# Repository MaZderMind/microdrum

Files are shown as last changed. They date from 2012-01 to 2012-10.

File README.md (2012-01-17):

# MicroDrum - Ein Mikrocontroller-Basierter Drum-Computer
Dies ist das Sourcecode-Repo des [Microdum-Projektes](http://microdrum.wordpress.com/). Die Hardware-Spezifikationen und Software-Komponenten werden hier veröffentlicht, Hintergründe und Geschichte können im [Blog](http://microdrum.wordpress.com/) nachgelesen werden.

## Kontakt
Wenn du Fragen hast, melde dich bei microdrum@mazdermind.de oder benutze das Github-Nachrichten-System

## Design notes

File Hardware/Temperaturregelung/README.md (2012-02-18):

# Anschlussplan für Temperaturregelung für Laminator
Dies ist der Schaltplan für die Temperaturregelung des Laminators verwendet wurde, mit welchem die Platinen des Drumcomputers hergestellt wurden.
Verwendet wird ein ATtiny13 zur Steuerung, eine 1N4148-Diode als Temperatursensor und ein S202S02 Optotriac zum steuern der Heizung.
Mehr Infos über den Aufbau des Gerätes können im [Blog](http://microdrum.wordpress.com/2012/02/17/platinen-herstellen/) gefunden werden, die ursprüngliche Idee und Umsetzung stammt von [Thomas Pfeifer](http://thomaspfeifer.net/laminator_temperatur_regelung.htm).

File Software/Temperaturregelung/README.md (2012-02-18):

# Temperaturregelung für Laminator
Dies ist die Software des ATtiny13, welcher für die Temperaturregelung des Laminators verwendet wurde, mit welchem die Platinen des Drumcomputers hergestellt wurden.
Wichtig ist, dass der ATtiny13 auf 4.8 MHz internen Resonator gestellt wird, da sonst die timings für den Software-UART zu ungenau sind. Gegebenenfalls muss ein externer Quarzoszialtor verwendet werden.
Mehr Infos über den Aufbau des Gerätes können im [Blog](http://microdrum.wordpress.com/2012/02/17/platinen-herstellen/) gefunden werden, die ursprüngliche Idee und Umsetzung stammt von [Thomas Pfeifer](http://thomaspfeifer.net/laminator_temperatur_regelung.htm).

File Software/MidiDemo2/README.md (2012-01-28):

# MidiDemo 2
Sendet im durch den Host-Computer vorgegeben Takt eine Midi-Note, wobei die Instrumente zwischen 35 und 59 durchlaufen werden.
In dieser Demo wird der Sende- und der Empfangsteil verwendet. Für weitere Informationen bitte das [Blog](http://microdrum.wordpress.com/2012/01/18/prototyp/) konsultieren.

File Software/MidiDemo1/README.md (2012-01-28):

# MidiDemo 1
Sendet im 1/4 Sekunden Takt eine Midi-Note an den Host-Computer, wobei die Instrumente zwischen 35 und 59 durchlaufen werden.
In dieser Demo wird nur der Sendeteil verwendet. Für weitere Informationen bitte das [Blog](http://microdrum.wordpress.com/2012/01/18/prototyp/) konsultieren.

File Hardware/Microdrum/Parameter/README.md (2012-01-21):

# MicroDrum - Parameter-Board
Dieser Ordner enthält Schemazeichnung und Platinenlayouts für die Parameter-Boards. Ein solches Board ist mit je 16 Drehpotentiometern bestückt und bietet dem Nutzer die Möglichkeit, die Klang-Parameter der einzelnen Instrumente zu konfigurieren.

## Aufbau
Damit der Atmel so viele analoge Signale (8×4 = 32) überhaupt verarbeiten kann, kommen [74HC4051](http://www.datasheetcatalog.org/datasheet/philips/74HC4051.pdf) 8-Kanal Analog Multiplexer/Demultiplexer zum Einsatz. Bei diesen Bauteilen wird mit 3 digitalen Leitungen einer der 8 Eingangspins gewählt, welcher dann mit dem Ausgangsport verbunden wird.

Wir verwenden 4 solcher ICs, deren Auswahlports jeweils verbunden sind, um mit 3 digitalen und 4 analogen Eingängen an der MCU alle 32 Potis messen zu können. Dazu werden zwei dieser Platinen benötigt, die je 16 Potis und 2 Multiplexer beinhalten.

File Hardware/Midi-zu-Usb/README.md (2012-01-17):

# MicroDrum - Midi-zu-Usb-Brücke
Dieser Ordner enthält die Schemazeichnung für den Anschluss der Midi-zu-Usb-Brücke an den Atmel-Controller und den PC. Weitere Informationen über die Bedeutung der einzelnen Pins gibt der [Blog-Artikel über die Midi-zu-Usb-Brücke](http://microdrum.wordpress.com/2012/01/16/midi-zu-usb-brucke/) auskunft.

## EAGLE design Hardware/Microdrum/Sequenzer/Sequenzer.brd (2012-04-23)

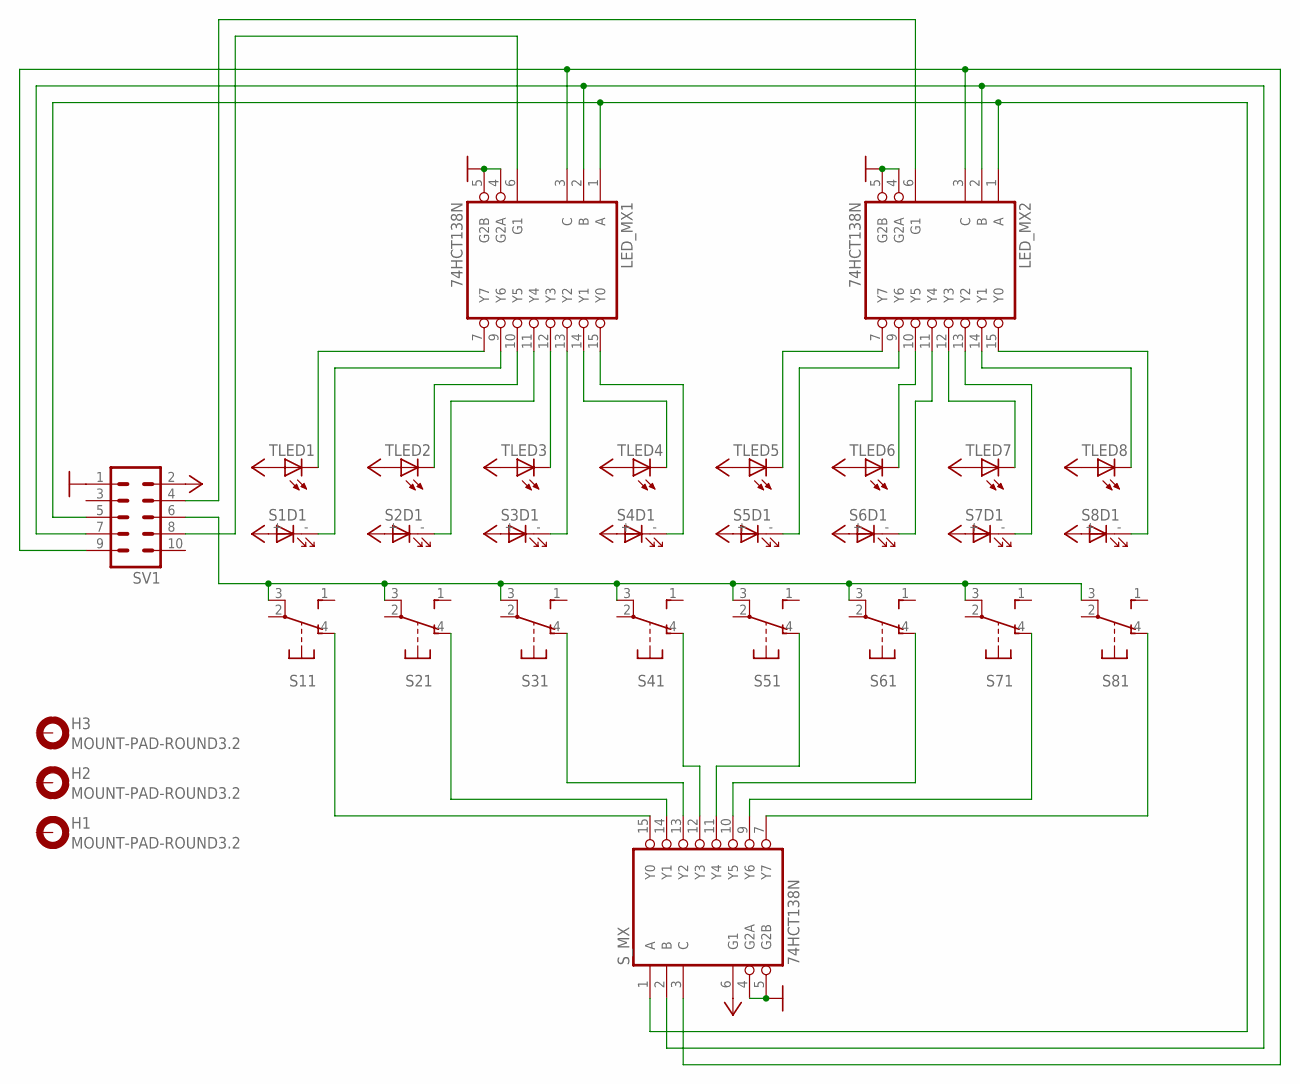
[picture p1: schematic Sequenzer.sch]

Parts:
H1, H2, H3: MOUNT-PAD-ROUND3.2; 3,2-PAD
LED_MX1, LED_MX2: 74HCT138N; DIL16
S1, S2, S3, S4, S5, S6, S7, S8: SRKL
SV1: ML10
S_MX: 74HCT138N; DIL16
TLED1, TLED2, TLED3, TLED4, TLED5, TLED6, TLED7, TLED8: LED3MM

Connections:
1: LED_MX1.1 (A), LED_MX2.1 (A), SV1.5, S_MX.1 (A)
2: LED_MX1.2 (B), LED_MX2.2 (B), SV1.7, S_MX.2 (B)
3: LED_MX1.3 (C), LED_MX2.3 (C), SV1.9, S_MX.3 (C)
GND: LED_MX1.4 (G2A), LED_MX1.5 (G2B), LED_MX1.8 (GND), LED_MX2.4 (G2A), LED_MX2.5 (G2B), LED_MX2.8 (GND), SV1.1, S_MX.4 (G2A), S_MX.5 (G2B), S_MX.8 (GND)
MX1EN: LED_MX1.6 (G1), SV1.8
MX2EN: LED_MX2.6 (G1), SV1.4
unnamed: S8.4 (O), S_MX.7 (Y7)
unnamed: S7.4 (O), S_MX.9 (Y6)
unnamed: S6.4 (O), S_MX.10 (Y5)
unnamed: S5.4 (O), S_MX.11 (Y4)
unnamed: S4.4 (O), S_MX.12 (Y3)
unnamed: S3.4 (O), S_MX.13 (Y2)
unnamed: S2.4 (O), S_MX.14 (Y1)
unnamed: S1.4 (O), S_MX.15 (Y0)
SLED: LED_MX1.13 (Y2), S3.- (C)
SLED1: LED_MX1.9 (Y6), S1.- (C)
SLED2: LED_MX1.11 (Y4), S2.- (C)
SLED4: LED_MX1.15 (Y0), S4.- (C)
SLED5: LED_MX2.9 (Y6), S5.- (C)
SLED6: LED_MX2.11 (Y4), S6.- (C)
SLED7: LED_MX2.13 (Y2), S7.- (C)
SLED8: LED_MX2.15 (Y0), S8.- (C)
S_SENSE: S1.3, S2.3, S3.3, S4.3, S5.3, S6.3, S7.3, S8.3, SV1.6
TLED1: LED_MX1.7 (Y7), TLED1.K (C)
TLED2: LED_MX1.10 (Y5), TLED2.K (C)
TLED3: LED_MX1.12 (Y3), TLED3.K (C)
TLED4: LED_MX1.14 (Y1), TLED4.K (C)
TLED5: LED_MX2.7 (Y7), TLED5.K (C)
TLED6: LED_MX2.10 (Y5), TLED6.K (C)
TLED7: LED_MX2.12 (Y3), TLED7.K (C)
TLED8: LED_MX2.14 (Y1), TLED8.K (C)
VCC: LED_MX1.16 (VCC), LED_MX2.16 (VCC), S1.+ (A), S2.+ (A), S3.+ (A), S4.+ (A), S5.+ (A), S6.+ (A), S7.+ (A), S8.+ (A), SV1.2, S_MX.6 (G1), S_MX.16 (VCC), TLED1.A, TLED2.A, TLED3.A, TLED4.A, TLED5.A, TLED6.A, TLED7.A, TLED8.A

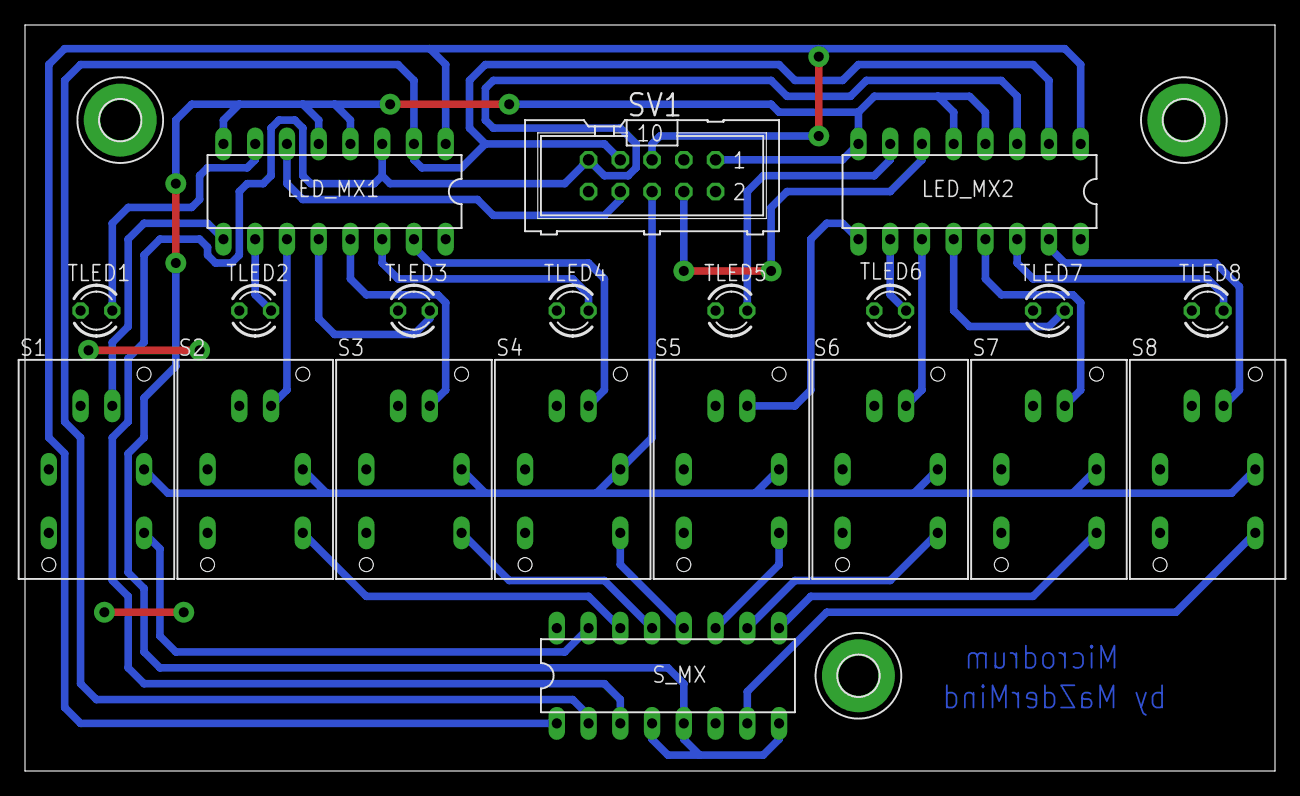
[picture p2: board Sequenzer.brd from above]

Board: 2 copper layers, 100.0 x 59.7 mm, 23 parts (0 on the bottom side), 32 nets.

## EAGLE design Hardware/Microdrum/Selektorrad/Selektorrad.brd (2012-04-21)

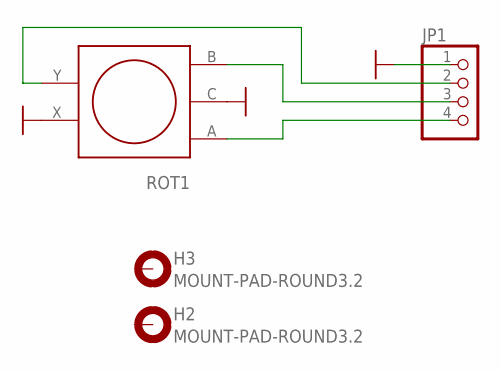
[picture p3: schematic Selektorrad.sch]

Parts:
H2, H3: MOUNT-PAD-ROUND3.2; 3,2-PAD
JP1: PINHD-1X4; 1X04
ROT1: STEC12E08; EC12E24244

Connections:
GND: JP1.1, ROT1.C, ROT1.X
unnamed: JP1.3, ROT1.B
unnamed: JP1.4, ROT1.A
unnamed: JP1.2, ROT1.Y

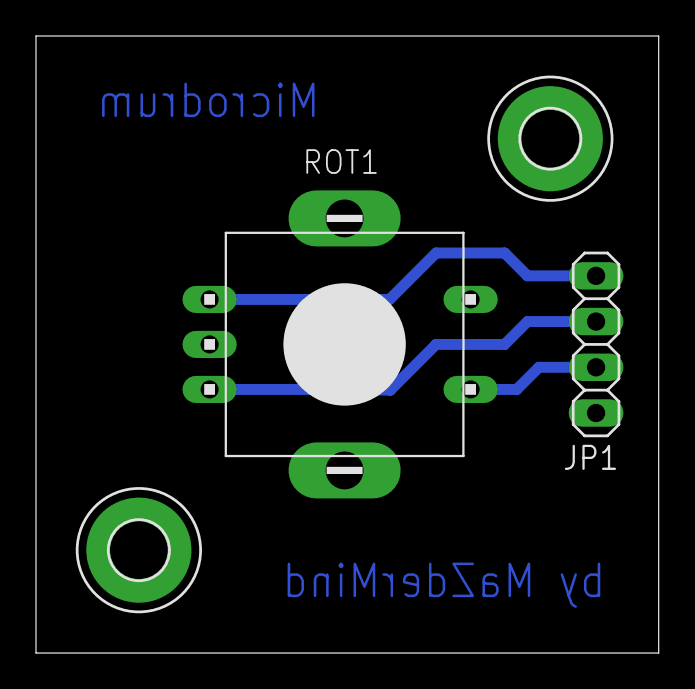
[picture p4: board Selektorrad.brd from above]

Board: 2 copper layers, 34.6 x 34.3 mm, 4 parts (0 on the bottom side), 4 nets.

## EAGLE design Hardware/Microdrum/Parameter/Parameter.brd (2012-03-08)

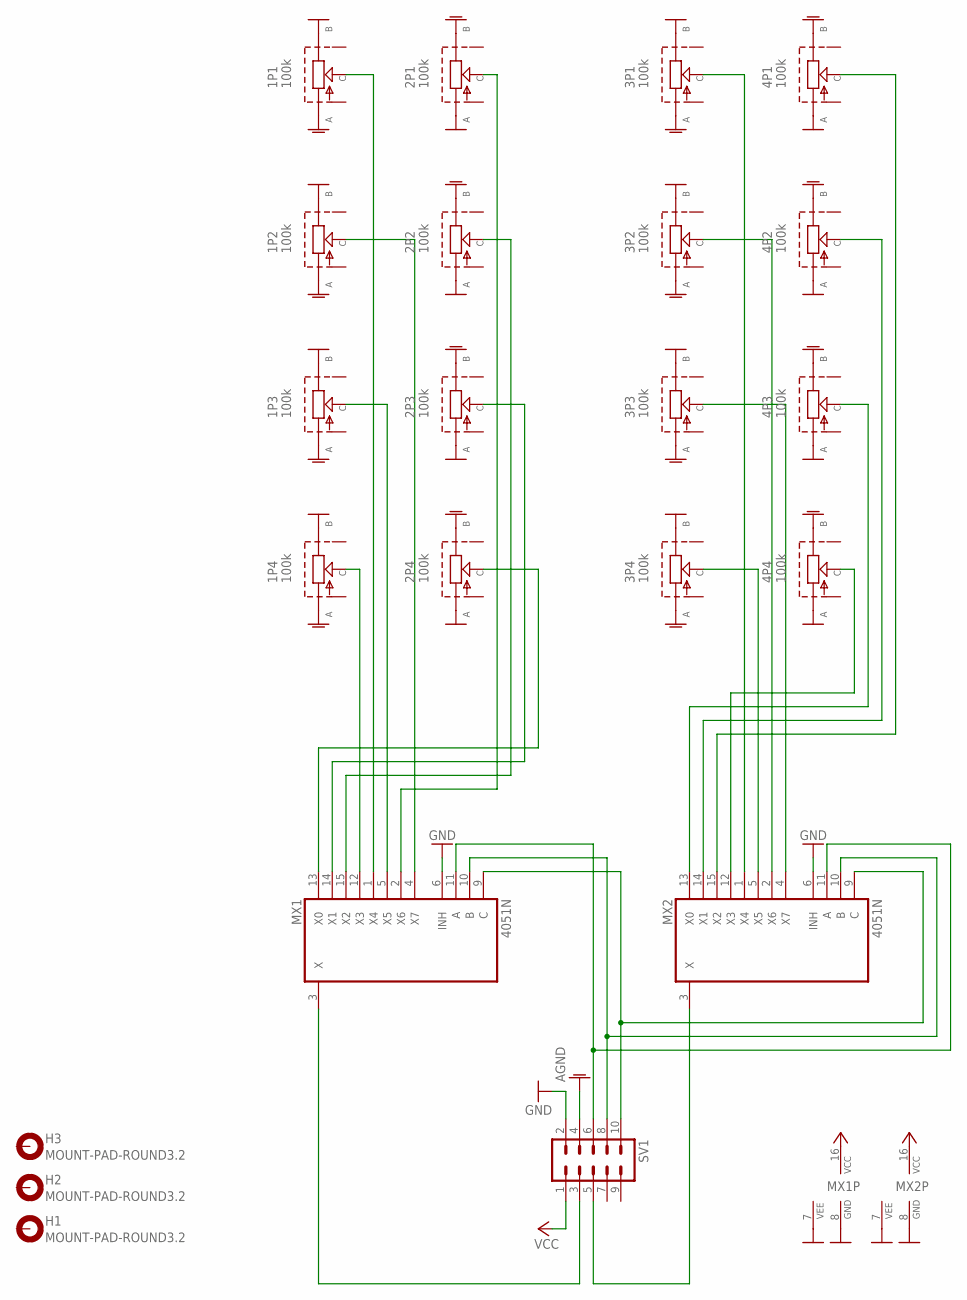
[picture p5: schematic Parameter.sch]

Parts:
1P1, 1P2, 1P3, 1P4, 2P1, 2P2, 2P3, 2P4, 3P1, 3P2, 3P3, 3P4, 4P1, 4P2, 4P3, 4P4: 100k; RK09K113
H1, H2, H3: MOUNT-PAD-ROUND3.2; 3,2-PAD
MX1, MX2: 4051N; DIL16
SV1: ML10

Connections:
0MX1: 2P4.C, MX1.13 (X0)
0MX2: 4P3.C, MX2.13 (X0)
1MX1: 2P3.C, MX1.14 (X1)
1MX2: 4P2.C, MX2.14 (X1)
2MX1: 2P2.C, MX1.15 (X2)
2MX2: 4P1.C, MX2.15 (X2)
3MX1: 1P4.C, MX1.12 (X3)
3MX2: 4P4.C, MX2.12 (X3)
4MX1: 1P1.C, MX1.1 (X4)
4MX2: 3P1.C, MX2.1 (X4)
5MX1: 1P3.C, MX1.5 (X5)
5MX2: 3P4.C, MX2.5 (X5)
6MX1: 2P1.C, MX1.2 (X6)
6MX2: 3P2.C, MX2.2 (X6)
7MX1: 1P2.C, MX1.4 (X7)
7MX2: 3P3.C, MX2.4 (X7)
A: MX1.11 (A), MX2.11 (A), SV1.6
AGND: 1P1.A, 1P2.A, 1P3.A, 1P4.A, 2P1.B, 2P2.B, 2P3.B, 2P4.B, 3P1.A, 3P2.A, 3P3.A, 3P4.A, 4P1.B, 4P2.B, 4P3.B, 4P4.B, SV1.4
B: MX1.10 (B), MX2.10 (B), SV1.8
C: MX1.9 (C), MX2.9 (C), SV1.10
GND: 1P1.B, 1P2.B, 1P3.B, 1P4.B, 2P1.A, 2P2.A, 2P3.A, 2P4.A, 3P1.B, 3P2.B, 3P3.B, 3P4.B, 4P1.A, 4P2.A, 4P3.A, 4P4.A, MX1.6 (INH), MX1.7 (VEE), MX1.8 (GND), MX2.6 (INH), MX2.7 (VEE), MX2.8 (GND), SV1.2
VCC: MX1.16 (VCC), MX2.16 (VCC), SV1.1
X1: MX1.3 (X), SV1.3
X2: MX2.3 (X), SV1.5

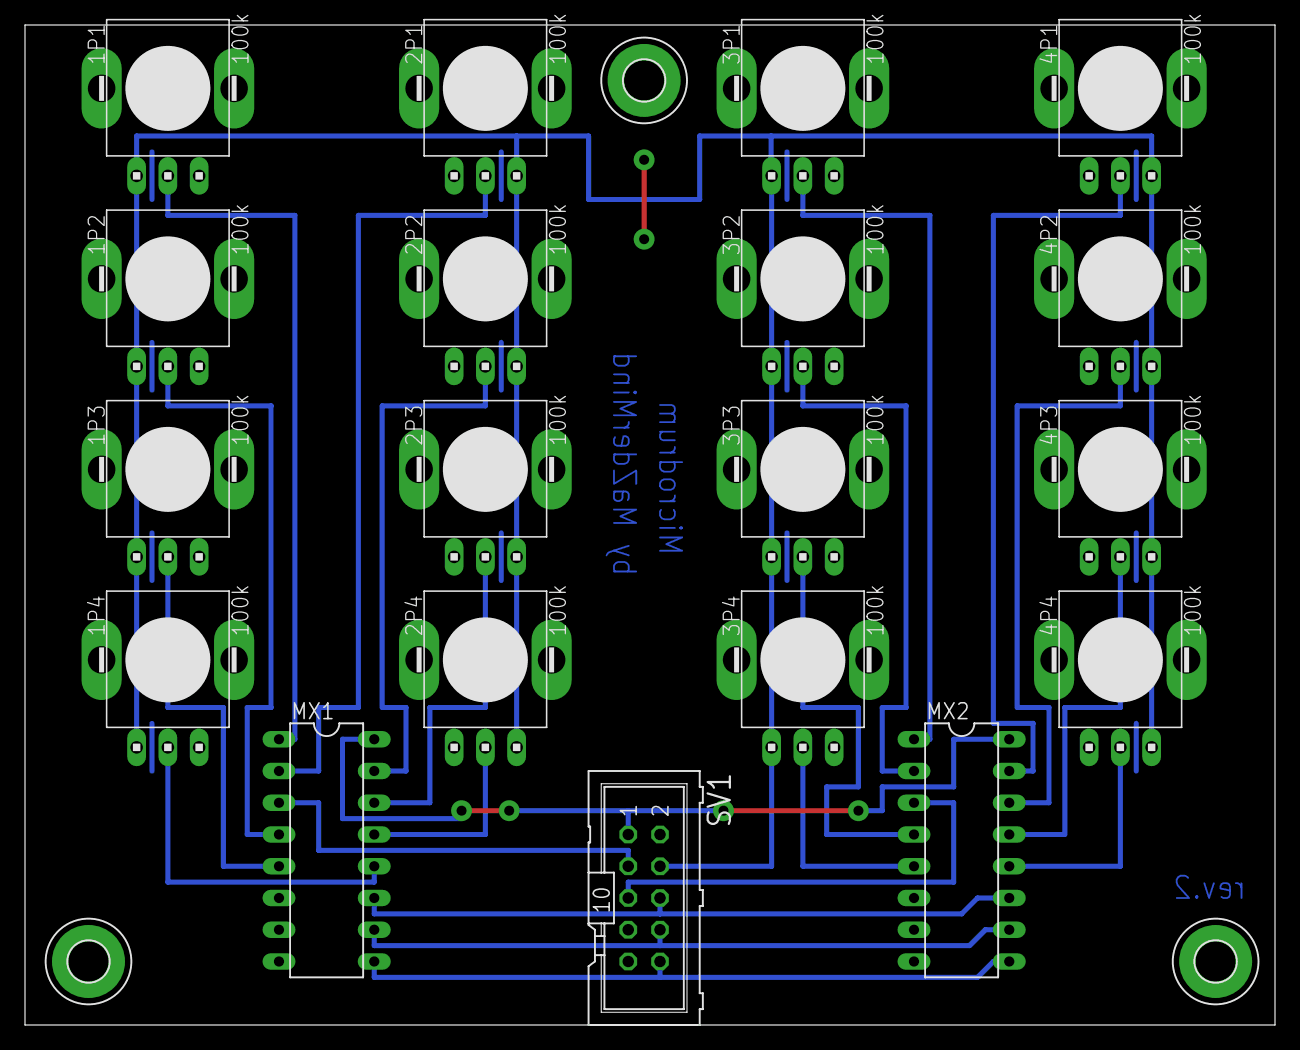
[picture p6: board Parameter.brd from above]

Board: 2 copper layers, 100.0 x 80.0 mm, 22 parts (0 on the bottom side), 24 nets.

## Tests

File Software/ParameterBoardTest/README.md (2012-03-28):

# Testprogramm für das Parameter-Board
Liest alle 16 Potentiometer aus, normalisiert die Werte auf einen Bereich von 0-255 und sendet diese per UART 9600 Baud 8N1 an den Computer.
Mit den Processing-Skripten im ProcessingVisualize-Ordner können die empfangenen Daten schön aufbereitet und visuell dargestellt werden.

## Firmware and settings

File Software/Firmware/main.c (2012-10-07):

/**
 * @file
 * Hauptdatei der Microdrum-Firmware
 *
 * diese Datei kombiniert alle einzelnen Komponenten der Firmware zu einem sinnvollen Programm.
 */

#include <avr/pgmspace.h>

#include "bits.h"
#include "lcd.h"
#include "io_config.h"
#include "io.h"
#include "io_selector.h"
#include "io_parameter.h"
#include "io_sequencer.h"
#include "midi.h"
#include "instrument_names.h"

// Forwärts-Deklaration der Event-Handler
void io_selector_pressed(void);
void io_selector_released(void);
void io_selector_left(void);
void io_selector_right(void);
void io_parameter_changed(uint8_t parameter, uint8_t value);
void midi_clock(uint8_t);

// Forwärts-Deklaration der Instrumenten-Anzeige-Routine
void print_selected_instrument(void);

/**
 * Mit dem Selektorrad ausgewähltes Instrument
 */
uint8_t selected_instrument = 0;

/**
 * Einstiegspunkt des Hauptprogramms
 */
int __attribute__((OS_main))
main(void)
{
	// Ein- & Ausgabe aktivieren
	io_init();

	// Event-Handler für Ein- & Ausgabe setzen
	io_selector_set_pressed_handler(io_selector_pressed);
	io_selector_set_released_handler(io_selector_released);
	io_selector_set_left_handler(io_selector_left);
	io_selector_set_right_handler(io_selector_right);
	io_parameter_set_changed_handler(io_parameter_changed);

	// Das LCD-Display aktivieren
	lcd_init();

	// Programmnamen ausgeben
	lcd_pstring(PSTR("The Microdrum"));

	// aktuellen Instrumentennamen ausgeben
	print_selected_instrument();

	// Midi aktivieren
	midi_init();

	// den Midi-Clock Callback definieren
	//   er soll alle 6 Midi-Clocks aufgerufen werden (das entspricht 16tel Noten),
	//   dabei sollen 8 Steps durchgezählt werden (von 0 bis 7)
	//     Würde das Steps-Zählen mit einer lokalen Variable gemacht, gäbe es Probleme
	//     beim Clock-Reset (neu Aufsetzen nach Pause oder Spulen)
	midi_set_clock_interrupt(midi_clock, 6, N_STEPS);

	// Das Hauptprogramm versinkt in einer Endlosschleife, welche die Eingaben der
	// Buttons abnimmt, die LEDs ansteuert und Änderungen an den Drehknöpfen
	// abliest.
	// Unterbrochen wird es durch Midi-Eingaben (siehe midi.c), wozu auch
	// Midi-Clock-Nachrichten gehören. Diese unterbrechen den normalen Programmablauf
	// und senden entsprechend dem aktuellen Zustand Midi-Noten zurück.
	for(;;) io_sync();

	// Programmende
	return 0;
}

/**
 * Das aktuell ausgewählte Instrument auf dem LCD ausgeben
 */
void print_selected_instrument(void)
{
	lcd_setcursor(0, 1);
	lcd_uint8(selected_instrument + 1);
	lcd_pstring(PSTR("/8 "));
	lcd_pstring(names[selected_instrument]);
	lcd_space(5);
}

/**
 * Event-Handler für das Niederdrücken des Selektorrads
 *
 * @see io_selector_set_released_handler
 */
void io_selector_pressed(void)
{
	lcd_setcursor(0, 2);
	lcd_pstring(PSTR("pressed"));
}

/**
 * Event-Handler für das Loslassen des Selektorrads nach dem Niederdrücken
 *
 * @see io_selector_set_pressed_handler
 */
void io_selector_released(void)
{
	lcd_setcursor(0, 2);
	lcd_space(7);
}

/**
 * Event-Handler, der aufgerufen wird, wenn das Selektorrad einen Schritt
 * nach links gedreht wurde
 *
 * @see io_selector_set_left_handler
 */
void io_selector_left(void)
{
	if(selected_instrument == 0)
		selected_instrument = N_INSTRUMENTS-1;
	else
		selected_instrument--;

	print_selected_instrument();
}

/**
 * Event-Handler, der aufgerufen wird, wenn das Selektorrad einen Schritt
 * nach rechts gedreht wurde
 *
 * @see io_selector_set_right_handler
 */
void io_selector_right(void)
{
	if(selected_instrument == N_INSTRUMENTS-1)
		selected_instrument = 0;
	else
		selected_instrument++;

	print_selected_instrument();
}

/**
 * Event-Handler, der aufgerufen wird, wenn sich ein Parameter geändert hat.
 * Als Antwort wird eine Midi-CC-Nachricht gesendet
 *
 * @see io_parameter_set_changed_handler
 */
void io_parameter_changed(uint8_t parameter, uint8_t value)
{
	midi_cc(parameter, value);
}

/**
 * Event-Handler, der aufgerufen wird, wenn eine gewisse Anzahl von
 * Midi-Clock-Nachrichten registriert wurden.
 *
 * Achtung: eine Interrupt-Routine
 *
 * @see midi_set_clock_interrupt
 */
void midi_clock(uint8_t beat)
{
	io_sequencer_set(beat);
	midi_detrigger_instruments();

	switch(beat)
	{
		case 0: {
			midi_trigger_instrument(0, 70); // Bass Drum
			break;
		}

		case 1: {
			break;
		}

		case 2: {
			midi_trigger_instrument(5, 70); // Closed Hi Hat
			break;
		}

		case 3: {
			break;
		}

		case 4: {
			midi_trigger_instrument(1, 70); // Snare Drum
			midi_trigger_instrument(2, 70); // Mid-Tom
			break;
		}

		case 5: {
			break;
		}

		case 6: {
			midi_trigger_instrument(5, 70); // Closed Hi Hat
			break;
		}

		case 7: {
			break;
		}

		case 8: {
			midi_trigger_instrument(0, 70); // Bass Drum
			break;
		}

		case 9: {
			break;
		}

		case 10: {
			midi_trigger_instrument(6, 70); // Open Hi Hat
			break;
		}

		case 11: {
			break;
		}

		case 12: {
			midi_trigger_instrument(1, 70); // Snare Drum
			midi_trigger_instrument(2, 70); // Mid-Tom
			break;
		}

		case 13: {
			break;
		}

		case 14: {
			midi_trigger_instrument(5, 70); // Closed Hi Hat
			break;
		}

		case 15: {
			break;
		}
	}
}

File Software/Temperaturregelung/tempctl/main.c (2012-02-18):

#include <util/delay.h>
#include <avr/pgmspace.h>
#include "softuart.h"
#include "io.h"

// destination adc value
#define Vshould 78

// main routine
int main(void)
{
	// initiate software-uart for serial communication
	softuart_init();
	
	// initialize input and output ports
	io_init();
	
	struct {
		unsigned heating:1;
		unsigned ready:1;
	} state;
	
	// pwm-counter
	uint8_t pwm_ctr = 0;
	
	// while .. forever
    while(1)
    {
		// read temp
		uint16_t val = io_get_temp_adc();
		
		// detect sensor shortage or breakage
		if(val < 24 || val > 1000)
		{
			// write message to serial
			softuart_puts_p(PSTR("ACD-Value out of range: "));
			softuart_puts_uint16(val);
			softuart_putc('\n');
			
			// turn heater off
			io_set_heating(0);
			
			// make ready-led blink
			io_set_ready(0);
			_delay_ms(250);
			io_set_ready(1);
			_delay_ms(250);
			
			// try again
			continue;
		}
		
		// pwm switching difference
		uint8_t pwm = 0;
		if(val > Vshould)
		{
			pwm = val - Vshould;
		}
		
		// pwm switch
		if (pwm < pwm_ctr)
		{
			state.heating = 0;
		}
		else
		{
			state.heating = 1;
		}
		
		// pwm increases with the temperature rising
		// 11+ = heating is always-on
		// 5 = heating is 1/2 the time on
		// 0 = heating is always-off
		if(pwm < 5)
		{
			state.ready = 1;
		}
		else if(pwm > 8)
		{
			state.ready = 0;
		}			
				
		// pwm counter increment
		if(++pwm_ctr >= 10)
			pwm_ctr = 0;
		
		// set heater status
		io_set_heating(state.heating);
		
		// set ready status
		io_set_ready(state.ready);
		
		// write status to serial
		softuart_puts_p(PSTR("ADC-Value: "));
		softuart_puts_uint16(val);
		softuart_puts_p(PSTR(", ADC-Goal: "));
		softuart_puts_uint16(Vshould);
		softuart_puts_p(PSTR(", Ready: "));
		softuart_puts_uint16(state.ready);
		softuart_puts_p(PSTR(", Heating: "));
		softuart_puts_uint16(state.heating);
		softuart_putc('\n');
		
		// wait 1/4 second
		_delay_ms(250);
    }
	
	// end of program
	return 0;
}

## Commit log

2012-01-17 Quelldatei für die Grafik überden Anschluss der Midi-zu-Usb-Brücke
    [Midi-zu-Usb.sch]
2012-01-17 Layout und Schematik eines Parameter-Boards mit 8 Potis
    [Parameter-Board-8.brd, Parameter-Board-8.sch]
2012-01-17 Textebenen hinzufügen
    [Parameter-Board-8.brd]
2012-01-17 Verweis auf ein Datasheet mit Darstellung der PDIP-Gehäuseform ändern
2012-01-19 move board to the left and make it smaller
    [Parameter-Board-8.brd]
2012-01-19 move text and add restrict-polygons
    [Parameter-Board-8.brd]
2012-01-19 Board-Layout und Schematik mit 16 Potentiometern und 2 Multiplex-ICs
    [Parameter-Board.brd, Parameter-Board.sch]
2012-01-19 VEE ist die negative Referenzspannung, welche in unserem Fall GND ist. Die Referenz-Voltage des MCU ist hingegen mit AGND verbunden.
    [Parameter-Board.brd, Parameter-Board.sch]
2012-01-19 fix clearance problem
    [Parameter-Board.brd]
2012-01-21 Das komplette Board wurde neu geroutet, so dass keine Top-Layer-Brücke nötig und die Leiterbahnführung einheitlicher ist
    [Parameter-Board.brd, Parameter-Board.sch]
2012-01-21 altes Board mit 8 Potis löschen
    [Parameter-Board-8.brd, Parameter-Board-8.sch]
2012-01-21 Das Mounthole wurde zwischen den Potentiometern zentriert
    [Parameter-Board.brd]
2012-01-22 Test-Programm zum ansteuern des LCDs und der Midi-Brücke
2012-01-28 Who? Wo war die Datei denn hin?
2012-01-28 zweite Midi-Demo, welche die Midi-Clock des Host-Computers benutzt, um die generieten Noten zu steuern
2012-02-18 Sourcecode und Schaltplan für Laminator-Temperaturregelung
    [tempctl.sch]
2012-03-06 Endgültiges Boardlayout
    [Parameter-Board.brd, Parameter-Board.sch]
2012-03-06 Information zu Revision
    [Parameter-Board.brd]
2012-03-08 Wenn die drei Bahnenden den gleichen Winkel haben, schaut's einfach schöner aus
    [Parameter-Board.brd]
2012-03-08 einfacher Schaltplan zur Beschreibung der Belichterplatinen
    [Belichter-Platinen.sch]
2012-03-15 Testdatei für Belichtungsreihe
    [Belichtertest.brd]
2012-03-26 Ordnerstruktur aufgeräumt, damit besser zwischen den Platinen und Schemata des Projektes und denen im weiteren Umfeld der Herstellung angefertigten unterschieden werden kann.
    [Parameter-Board.brd, Parameter-Board.sch, Selektorrad.brd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]
2012-03-28 Testprogramm für das Parameter-Board
2012-04-12 minimized selector board
    [Selektorrad.brd, Selektorrad.sch]
2012-04-18 Prototyp der Sequenzer Platine
    [Sequenzer.brd, Sequenzer.sch]
2012-04-18 Parameter-Board umbenennen
    [Parameter.brd, Parameter.sch]
2012-04-18 Leichte veränderungen in Routing und Positionierung
    [Selektorrad.brd]
2012-04-19 Langsam nimmt es Form an
    [Sequenzer.brd, Sequenzer.sch]
2012-04-21 Vorläufig fertiges Layout
    [Sequenzer.brd, Sequenzer.sch]
2012-04-21 Leicht geänderte Routenführung
    [Selektorrad.brd]
2012-04-21 Width wieder zurückgeändert, Dimension begradigt
    [Sequenzer.brd]
2012-04-21 Layer-Sichtbarkeit auf Standard
    [Sequenzer.brd]
2012-04-21 Label-Placement im Schaltplan
    [Sequenzer.brd, Sequenzer.sch]
2012-04-21 Route aus optischen Gründen geändert
    [Sequenzer.brd]
2012-04-23 Basisdateien für Demo-Firmware diesmal mit Linux-Toolchain (Makefiles und passender gitignore)
2012-04-23 Bohrlöcher
    [Sequenzer.brd, Sequenzer.sch]
2012-04-25 Basis des späteren Firmware-Frameworks
2012-04-25 I/O-Code aufräumen, Selektorrad abfragen und Instrumentenname anzeigen
2012-04-25 IO-Komponente für die Parameter-Boards aus dem entsprechenden Testcase
2012-04-26 Entprellen des Drehrads, umstellen auf Post-Select Post-SElect beudeutet, dass erst nach abschließen eines Schrittes des Drehrads gezählt wird, nicht gleich zu Beginn
2012-04-28 Endlich synchron und mit Song Position Pointer support
2012-04-29 Aufräumen des Clocking-Codes nach den Ergebnissen des Hack-Weekends verbessern der Synchronizität durch berechnen der Beat-Zahl aus dem Midi-Clock-Count Gegensteuern gegen Probleme mit zu kurzen Noten
    [main.c, midi.c]
2012-05-01 Reparieren und Optimieren der Clock-Routinen
2012-05-01 Besseres Instrumenten-Triggering und Clearing
2012-05-06 Dokumentation der Hauptdatei
2012-05-06 Hauptseite der Dokumentation
2012-05-06 Clean löscht auch die Dokumentation
2012-05-06 Kommentare um die Includes entfernen
2012-05-06 Dokumentation des Midi-Moduls
2012-05-06 die Bit-Helper-Macros benutzen
2012-05-06 Dokumentation der Bithelper-Makros
2012-05-06 Dokumentation des allgemeinen IO-Moduls
2012-05-06 Dokumentation der Selektorrad-Routinen
2012-05-06 Aufräumen der Dokumentation der LCD-Routinen für Doxygen
2012-05-06 Dokumentation der io_config-Datei
2012-08-27 enable parameter boards in test-setup
2012-08-27 fix parameter boards in test-setup
    [io.c, io.h, io_parameter.c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]
2012-08-27 move selector detection into the cycle-loop in order to avoid missing selector ticks
    [io.c]
2012-09-01 reduce memory footprint by splitting bits
2012-09-02 fix midi - argh\!
    [midi.c]
2012-09-12 only fetch the adc once, it's well - a little simpler
2012-09-12 adress both boards
2012-09-26 PD2 wird verwendet, um die Geschwindigkeit des Sync-Loops zu visualisieren
2012-09-26 Testen der Sequencer-LEDs
2012-09-30 Sauberes implementieren der Sync-Led
2012-09-30 parameter-state-management in die parameter-lib verlagern und auf events umstricken
2012-09-30 Pedantik- und Rechtschreib-Fehler beheben
2012-10-06 Doxygen die setbaud-Makros beibringen
2012-10-07 anpassen des presync-aufrufs
